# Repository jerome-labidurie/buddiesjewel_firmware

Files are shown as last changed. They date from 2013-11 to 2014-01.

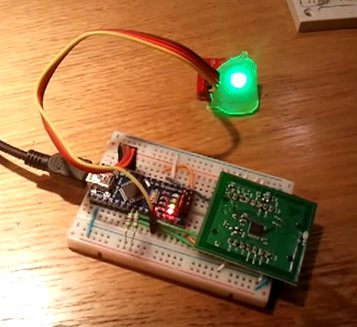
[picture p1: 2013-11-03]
hardware/Photos/Proto_v1_5.jpg

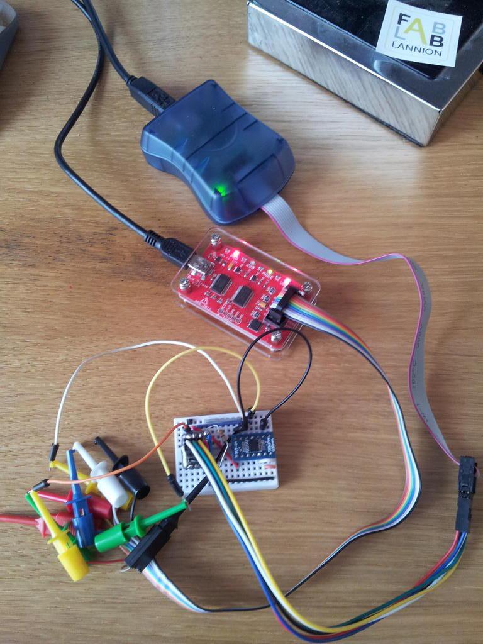
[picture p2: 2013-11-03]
hardware/Photos/Proto_v2.jpg

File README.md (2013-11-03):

buddiesjewel_firmware
=====================

Firmware (arduino, attiny45) for BuddiesJewel project

http://fablab-lannion.org/wiki/index.php?title=BuddiesJewel

* attiny45/ : firmware attiny45 et RF430CL330H
* BlinkM/ : archive de BlinkM et outils de flashage
* hardware/ : schémas
* serial2rgb/ : commande d'une led rgb par liason série (via arduino)
* tag2rgb/ : lecture couleur dans un tag et commande rgb (shield nfc reader)
* TI_dynamic_tag/ : utilisation par un arduino du RF430Cl330H

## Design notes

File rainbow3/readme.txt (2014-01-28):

/* ************************************************************ *
 *                    rainbow3                                  *
 *  README                                                      *
 *  desc: for attiny45 (8 Mhz), NeoPixel connected on pin 6     *
 *        run a rainbow of colors until detection of a pressure *
 *        on the push button (pin 5) that stops the rainbow on  *
 *        the current color.                                    *
 *        Another pressure detection will start over the rainbow*
 *                                                              *
 * pinout:                                                      *
 *               ______                                         *
 *        n/a --|1    8|-- Vcc                                  *
 *        n/a --|2    7|-- Debug LED                            *
 *        n/a --|3    6|-- NeoPixel Din                         *
 *        gnd --|4____5|-- push button                          *
 *                                                              *
 * ************************************************************ */

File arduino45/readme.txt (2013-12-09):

Use the attiny45 as an arduino (ie arduino libs)

Install
-------

Install attiny support for arduibo IDE
See here http://hlt.media.mit.edu/?p=1695
Or here http://code.google.com/p/arduino-tiny/
- board type: Attiny45 (internal 8MHz clock)
Burn bootloader (to set the fuses)

Install Adafruit NeoPixel lib
https://github.com/adafruit/Adafruit_NeoPixel

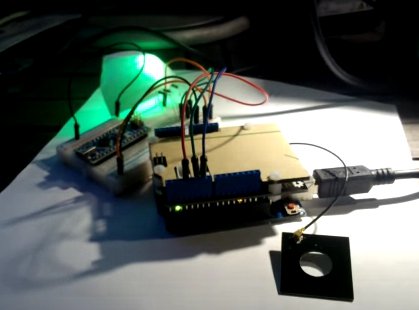
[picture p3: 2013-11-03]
hardware/Photos/Proto_v1.jpg

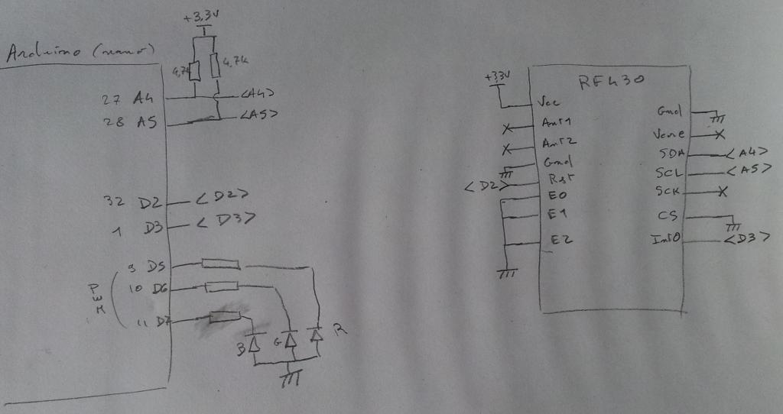
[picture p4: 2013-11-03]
hardware/schema_nano+rf430.jpg

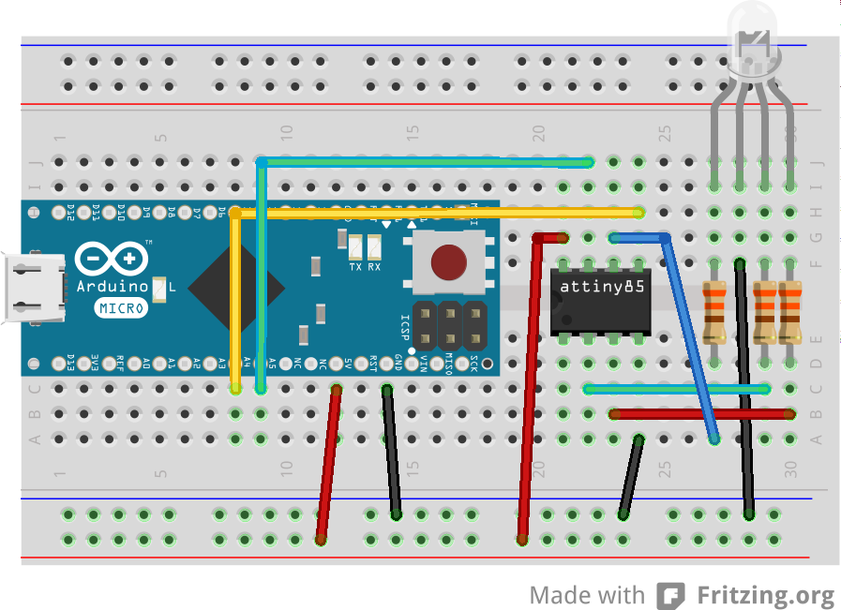
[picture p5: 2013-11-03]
hardware/arduino_BlinkM_bb.png

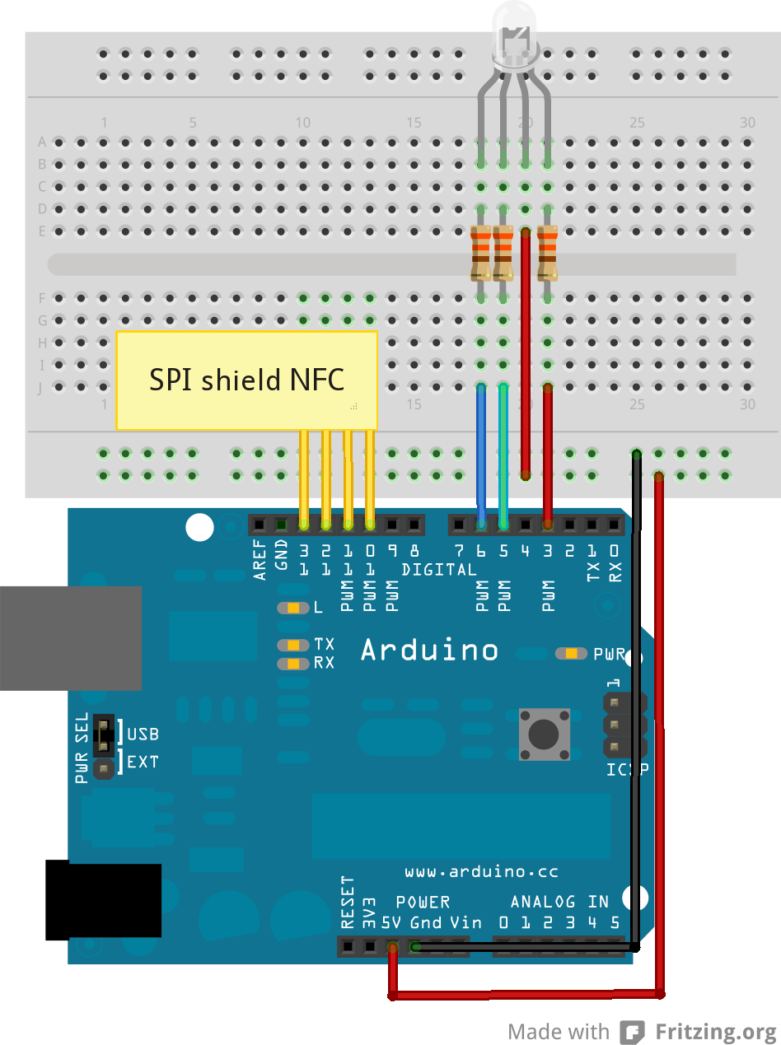
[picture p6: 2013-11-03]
hardware/tag2rgb_bb.png

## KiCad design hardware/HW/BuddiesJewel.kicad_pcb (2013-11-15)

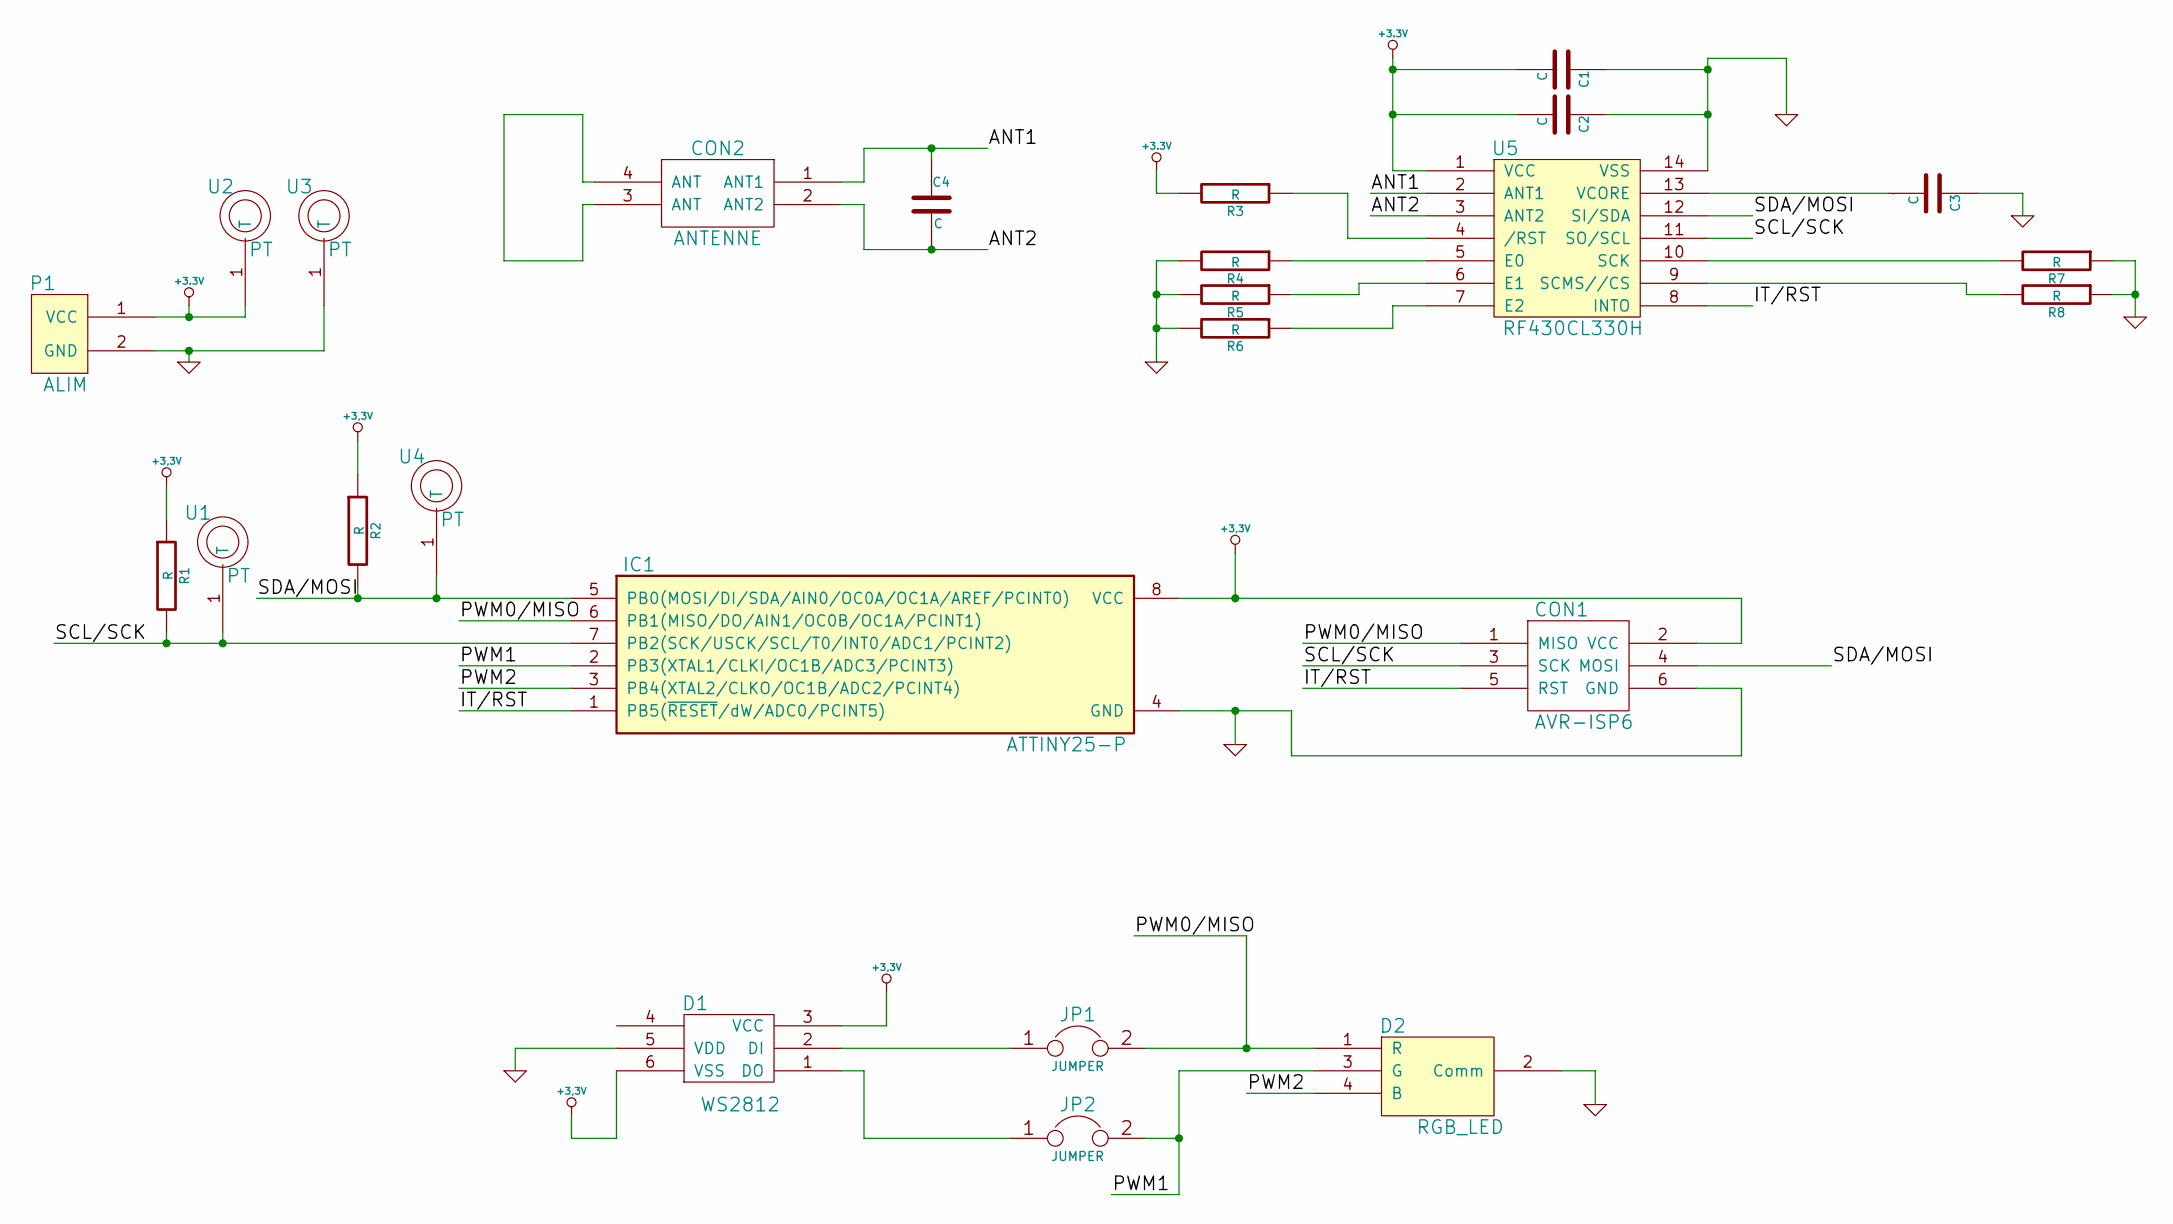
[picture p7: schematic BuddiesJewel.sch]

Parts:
C1, C2, C3, C4: C
CON1: AVR-ISP6
CON2: ANTENNE
D1: WS2812
D2: RGB_LED
IC1: ATTINY25-P; DIP8
JP1, JP2: JUMPER
P1: ALIM
R1, R2, R3, R4, R5, R6, R7, R8: R
U1, U2, U3, U4: PT
U5: RF430CL330H

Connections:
/ANT1: C4.1, CON2.1 (ANT1), U5.2 (ANT1)
/ANT2: C4.2, CON2.2 (ANT2), U5.3 (ANT2)
/IT/RST: CON1.5 (RST), IC1.1 (PB5(~RESET~/dW/ADC0/PCINT5)), U5.8 (INTO)
/PWM0/MISO: CON1.1 (MISO), D2.1 (R), IC1.6 (PB1(MISO/DO/AIN1/OC0B/OC1A/PCINT1)), JP1.2
/PWM1: D2.3 (G), IC1.2 (PB3(XTAL1/CLKI/OC1B/ADC3/PCINT3)), JP2.2
/PWM2: D2.4 (B), IC1.3 (PB4(XTAL2/CLKO/OC1B/ADC2/PCINT4))
/SCL/SCK: CON1.3 (SCK), IC1.7 (PB2(SCK/USCK/SCL/T0/INT0/ADC1/PCINT2)), R1.2, U1.1, U5.11 (SO/SCL)
/SDA/MOSI: CON1.4 (MOSI), IC1.5 (PB0(MOSI/DI/SDA/AIN0/OC0A/OC1A/AREF/PCI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), R2.2, U4.1, U5.12 (SI/SDA)
GND: C1.1, C2.1, C3.1, CON1.6 (GND), D1.5 (VDD), D2.2 (Comm), IC1.4 (GND), P1.2 (GND), R4.2, R5.2, R6.2, R7.1, R8.1, U3.1, U5.14 (VSS)
unnamed: R6.1, U5.7 (E2)
unnamed: R5.1, U5.6 (E1)
unnamed: R4.1, U5.5 (E0)
unnamed: D1.2 (DI), JP1.1
unnamed: R8.2, U5.9 (SCMS//CS)
unnamed: R7.2, U5.10 (SCK)
unnamed: R3.1, U5.4 (/RST)
unnamed: C3.2, U5.13 (VCORE)
unnamed: CON2.3 (ANT), CON2.4 (ANT)
unnamed: D1.1 (DO), JP2.1

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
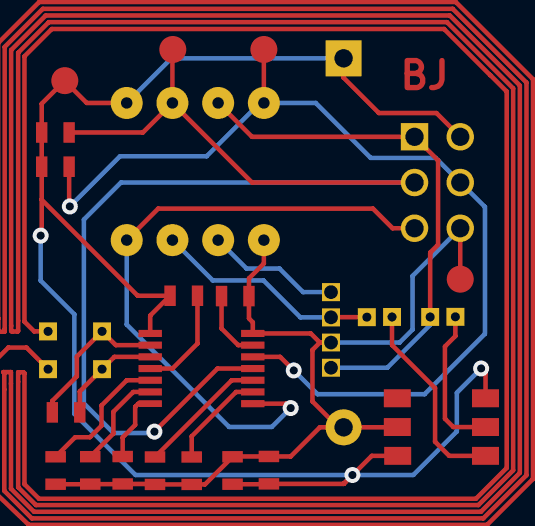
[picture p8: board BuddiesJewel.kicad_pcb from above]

Board: 2 copper layers, 25 parts (0 on the bottom side), 20 nets.

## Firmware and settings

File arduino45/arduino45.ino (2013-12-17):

/*********************************************************************
 * BuddiesJewel prototype with ATtiny45/RF430CL330H
 *********************************************************************
 * Copyright: (c) 2013 Jérôme Labidurie
 * Licence:   GNU General Public Licence version 3
 * Email:     jerome.labidurie at gmail.com
 *********************************************************************
 * This file is part of BuddiesJewel.
 * 
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
 * ATtiny45
 *                                      ---v---
 *         (PCINT5/RESET/ADC0/dW) PB5 -| 1   8 |- VCC
 *  (PCINT3/XTAL1/CLKI/OC1B/ADC3) PB3 -| 2   7 |- PB2 (SCK/USCK/SCL/ADC1/T0/INT0/PCINT2)
 *  (PCINT4/XTAL2/CLKO/OC1B/ADC2) PB4 -| 3   6 |- PB1 (MISO/DO/AIN1/OC0B/OC1A/PCINT1)
 *                                GND -| 4   5 |- PB0 (MOSI/DI/SDA/AIN0/OC0A/OC1A/AREF/PCINT0)
 *                                      -------
 * 
 * RF430CL330H
 *        ----v---
 *  Vcc -|  1  14 |- Gnd
 *   A1 -|  2  13 |- Vcore
 *   A2 -|  3  12 |- SDA
 * /RST -|  4  11 |- SCL
 *   E0 -|  4  10 |- SCK
 *   E1 -|  6   9 |- /CS
 *   E2 -|  7   8 |- Int
 *        --------
 * 
 * AT45    RF430   NeoPixel
 * -------------------
 * PB1 --- INT0
 * PB2 --- SCL
 * PB0 --- SDA
 * GND --- Gnd,E0,E1,E2,/CS,
 * PB4 ----------- In
 * 
 *********************************************************************/

#include <avr/io.h>
#include <util/delay.h>
#include <avr/interrupt.h>
#include <avr/sleep.h>

#include "usiTwiMaster.h"
#include "RF430CL330H.h"

#include <Adafruit_NeoPixel.h>
#include <EEPROM.h>

#define MESSAGEBUF_SIZE       10

#define NEO 4
#define QUICK 100

#define  CONTROL_REG_VALUE RF_ENABLE | INT_ENABLE | INTO_HIGH | INTO_DRIVE
// predefined colors
//      NAME      0xRRGGBB
#define BLUE      0x0000FF
#define GREEN     0x00FF00
#define RED       0xFF0000
#define YELLOW    0xFFFF00
#define CYAN      0x00FFFF
#define MAGENTA   0xFF00FF

// Parameter 1 = number of pixels in strip
// Parameter 2 = pin number (most are valid)
// Parameter 3 = pixel type flags, add together as needed:
//   NEO_KHZ800  800 KHz bitstream (most NeoPixel products w/WS2812 LEDs)
//   NEO_KHZ400  400 KHz (classic 'v1' (not v2) FLORA pixels, WS2811 drivers)
//   NEO_GRB     Pixels are wired for GRB bitstream (most NeoPixel products)
//   NEO_RGB     Pixels are wired for RGB bitstream (v1 FLORA pixels, not v2)
Adafruit_NeoPixel led = Adafruit_NeoPixel(1, NEO, NEO_GRB + NEO_KHZ800);

uint8_t temp = 0;               /** temporary variable */
uint16_t value = 0;             /** used to store read values from registers */
uint32_t savedColor = 0x000000; /** color read from eeprom */

/** do some quick blinks
 * @param n number of blinks
 * @param color the color to blink (created by Adafruit_NeoPixel.Color() )
 */
void quickBlink (uint8_t n, uint32_t color)
{
   while (n-- != 0)
   {
      led.setPixelColor (0, color );
      led.show();
      _delay_ms (QUICK);
      led.setPixelColor (0, 0 );
      led.show();
      _delay_ms (QUICK);
   }
} //quickBlink


/** read register from RF430
 * @param reg the register address to read. See RF430CL330H.h.
 * @param pValue pointer to the read value
 * @return USI_TWI_Get_State_Info. See usiTwiMaster.h for error codes.
 */
uint8_t readRegister (uint16_t reg, uint16_t* pValue)
{
   uint8_t messageBuf[MESSAGEBUF_SIZE];
   
   // write register adress
   messageBuf[0] = RF430_I2C_ADDRESS << TWI_ADR_BITS;
   messageBuf[1] = reg >> 8;
   messageBuf[2] = reg & 0xFF;
   USI_TWI_Start_Transceiver_With_Data( messageBuf, 3 );
   // read register
   messageBuf[0] = ( RF430_I2C_ADDRESS << TWI_ADR_BITS ) | (RF430_I2C_READBIT);
   USI_TWI_Start_Transceiver_With_Data( messageBuf, 3 );
   
   *pValue = (messageBuf[1] << 8) | messageBuf[2];
   
   return USI_TWI_Get_State_Info();
} // readRegister

/** read NFC data from RF430 
 * 
 * If active, RF must be disabled before. eg: writeRegister (CONTROL_REG, 0);
 * Note: offset+length must be < 0x0BFF. Else we go into registers.
 * 
 * @param offset the offset in NFC tag data
 * @param length the length to be read
 * @param data byte array for the read data. Must be at least length+1. Read data begins at data[1]
 * @return USI_TWI_Get_State_Info. See usiTwiMaster.h for error codes.
 * 
 */
uint8_t readData (uint16_t offset, uint16_t length, uint8_t* data)
{
   // write data address
   data[0] = RF430_I2C_ADDRESS << TWI_ADR_BITS;
   data[1] = offset >> 8;
   data[2] = offset & 0xFF;
   USI_TWI_Start_Transceiver_With_Data( data, 3 );
   // read register
   data[0] = ( RF430_I2C_ADDRESS << TWI_ADR_BITS ) | (RF430_I2C_READBIT);
   USI_TWI_Start_Transceiver_With_Data( data, length + 1 );

   return USI_TWI_Get_State_Info();
} // readData

/** write a register to RF430
 * @param reg the register address to write. See RF430CL330H.h.
 * @param value the value to be written.
 * @return USI_TWI_Get_State_Info. See usiTwiMaster.h for error codes.
 */
uint8_t writeRegister (uint16_t reg, uint16_t value)
{
   uint8_t messageBuf[MESSAGEBUF_SIZE];
   
   // write register adress
   messageBuf[0] = RF430_I2C_ADDRESS << TWI_ADR_BITS;
   messageBuf[1] = reg >> 8;
   messageBuf[2] = reg & 0xFF;
   messageBuf[3] = value & 0xFF;
   messageBuf[4] = value >> 8;
   USI_TWI_Start_Transceiver_With_Data( messageBuf, 5 );
   
   return USI_TWI_Get_State_Info();
} // writeRegister


/** Go to designated color
 * 
 * Fade from current color. Each component (R,G,B) are (inc|dec)remented
 * by one step up to the given color.
 * 
 * @param color to go
 * @param wait delay (ms) between each step
 */
void gotoColor (uint32_t color, uint8_t wait)
{
   uint32_t cColor = led.getPixelColor(0);  /** current color */
   uint8_t rc = cColor >> 16;               /** current red */
   uint8_t gc = cColor >> 8 & 0xFF;         /** current green */
   uint8_t bc = cColor & 0xFF;              /** current blue */
   int8_t  ri=1,gi=1,bi=1;                  /** inc/dec for each component */
   
   // compute inc or dec for each component
   if ( (rc) > (color>>16) ) {
      ri = -1;
   }
   if ( (gc) > (color>>8&0xFF) ) {
      gi = -1;
   }
   if ( (bc) > (color&0xFF) ) {
      bi = -1;
   }
   
   // goto
   while (cColor != color) {
      if (rc != (color>>16))
         rc += ri;
      if (gc != (color>>8&0xFF))
         gc += gi;
      if (bc != (color&0xFF))
         bc += bi;
      cColor = led.Color (rc,gc,bc);
      led.setPixelColor (0, cColor);
      led.show();
      delay(wait);
   }
} // gotoColor

/** interrupt service routine
 * called when PCINT changes state
 */
ISR(PCINT0_vect)
{
//    quickBlink (1, BLUE ); // quick 1 blue blink
   // nothing to do, we just wake up
   return;
} // ISR(PCINT0_vect) 

/****** MAIN ******/
   
void setup()
{
   led.begin();
   quickBlink (1, BLUE ); // quick 1 blue blink
   
   USI_TWI_Master_Initialise();
   temp = readRegister  (VERSION_REG, &value);
   quickBlink (value>>8,   BLUE );
   quickBlink (value&0xFF, BLUE );

   // read color from eeprom
   savedColor = ((uint32_t)EEPROM.read(0)<<16) | ((uint32_t)EEPROM.read(1)<<8) | EEPROM.read(2);
   
   // Initialize pixel to saved color
   gotoColor (savedColor,10);
   // TODO: Initialize NFC tag with color (and NDEF?)
   
   temp = writeRegister (INT_ENABLE_REG, EOW_INT_ENABLE);
   temp = writeRegister (CONTROL_REG,    CONTROL_REG_VALUE );
   temp = readRegister  (CONTROL_REG,    &value);
   
   /** Power budget reduction */
   ADCSRA &= ~_BV(ADEN);            // disable ADC
   ACSR   |=  _BV(ACD);             // switch Analog Comparator OFF
   // Configure Power Reduction Register (See p39)
   PRR    |=  _BV(PRADC) | _BV(PRTIM0); // switch off ADC clock, Timer0
   // disable BOD by software (timed sequence see p38)
   // useless if BOD not set by fuses
   sleep_bod_disable();


} // setup

void loop()
{
   uint8_t data[MESSAGEBUF_SIZE]; /** array to store read NDEF data */
   uint32_t readColor = 0;

   /** initialize attiny45 interrupts */
   PCMSK |= _BV(PCINT1); // enable interrupt for PCINT1
   GIMSK |= _BV(PCIE);   // enable Pin Change interrupts
   sei(); // enable global interrupts

   /** go to sleep */
   set_sleep_mode(SLEEP_MODE_PWR_DOWN); // sleep mode is set here
   sleep_enable();
   sleep_cpu(); // go to sleep

   // System continues execution here when wake up occurs
   cli();                // wake up here, disable interrupts
   GIMSK &= ~_BV(PCIE);  // disable PCIE
   sleep_disable();               
   sei();                // enable interrupts again (but PCIE is disabled from above)
//    quickBlink (1, GREEN);

   // Wait for no rf field present,
   // well not needed as EOW int occurs when RF field is off after a write
//    temp = readRegister  (CONTROL_REG,    &value);
//    while ( (value & RF_BUSY) != 0) {
//       _delay_ms (1);
//       temp = readRegister  (CONTROL_REG,    &value);
//    }
   // disable RF
   // TODO: we might only disable the right bit !
   temp = writeRegister (CONTROL_REG, 0x0);
   // ack every interrupts (yes this is a bit harsh)
   temp = writeRegister (INT_FLAG_REG, 0x00FF );
   // read ndef data mime type (should be "bijou")
   temp = readData (0x1C + 0x20, 6, data);
   if ( strncmp ((char*)data+1, "bijou", 5) == 0) {
      // 0x1C: NDEF begin 0x25: offset to color
      temp = readData (0x1C + 0x25, 4, data);
      readColor = led.Color (data[2], data[3], data[4]);
      gotoColor (readColor,10);
      // if needed, save new color in eeprom
      if (savedColor != readColor) {
         EEPROM.write(0, readColor >> 16);
         EEPROM.write(1, (readColor >> 8) & 0xFF);
         EEPROM.write(2, readColor & 0xFF);
         savedColor = readColor;
      }
   }
//    else quickBlink(1,RED);
   // enable RF
   temp = writeRegister (CONTROL_REG, CONTROL_REG_VALUE );
} // loop

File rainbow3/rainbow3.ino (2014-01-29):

#include <avr/io.h>
#include <avr/interrupt.h>
#include <Adafruit_NeoPixel.h>

#define RAINBOWING_LED_PIN 0      /* Physical Pin 5: for PCINT1: Play/Stop Pin      */
#define LED_PIN            1      /* Physical Pin 6: LED connection                 */
#define DEBUG_PIN          2      /* Physical Pin 7: debugging with a led:          */
                                  /*                 HIGH when the button is pushed */
                                  /*                 LOW  otherwise                 */ 
                                  
#ifdef TRUE
#  undef TRUE
#endif
#ifdef FALSE
#  undef FALSE
#endif
#ifdef UP
#  undef UP
#endif
#ifdef DOWN
#  undef DOWN
#endif

#define TRUE  0x01
#define FALSE 0x00
#define UP    1
#define DOWN  0

// Parameter 1 = number of pixels in led
// Parameter 2 = pin number (most are valid)
// Parameter 3 = pixel type flags, add together as needed:
//   NEO_KHZ800  800 KHz bitstream (most NeoPixel products w/WS2812 LEDs)
//   NEO_KHZ400  400 KHz (classic 'v1' (not v2) FLORA pixels, WS2811 drivers)
//   NEO_GRB     Pixels are wired for GRB bitstream (most NeoPixel products)
//   NEO_RGB     Pixels are wired for RGB bitstream (v1 FLORA pixels, not v2)
Adafruit_NeoPixel   led           = Adafruit_NeoPixel(1, LED_PIN, NEO_GRB + NEO_KHZ800);
volatile unsigned char rainbowing = TRUE;
volatile unsigned char flag       = DOWN; 
volatile unsigned char count      = 0; 

/** interrupt service routine
 * called when PCINT changes state
 */
void stop_rainbow()
{
   rainbowing=!rainbowing;
} // stop_rainbow()


void setup() {
  pinMode(DEBUG_PIN,OUTPUT);

  led.begin();
  led.show(); // Initialize all pixels to 'off'
  rainbowing = TRUE; // activate the rainbow 
  count=0;
  flag       = DOWN; // no detected interrupt yet
  attachInterrupt(RAINBOWING_LED_PIN, stop_rainbow, FALLING);
}

void loop() {
  uint8_t wait = 200;  

  if(digitalRead(RAINBOWING_LED_PIN)==LOW) {
    digitalWrite(DEBUG_PIN,LOW);
  }
  else {
    digitalWrite(DEBUG_PIN,HIGH);
  }
  
  if(rainbowing) {
    led.setPixelColor(0, Wheel(count++));
    led.show();
  }
  delay(wait);
}


// Input a value 0 to 255 to get a color value.
// The colours are a transition r - g - b - back to r.
uint32_t Wheel(byte WheelPos) {
  if(WheelPos < 84) {
    return led.Color(255 - WheelPos * 3, 0, WheelPos * 3);
  } else if(WheelPos >=84 && WheelPos < 88) { // fix blue color
    return led.Color(0, 0, 255);  
  } else if(WheelPos < 170) {
    WheelPos -= 85;
    return led.Color(0, WheelPos * 3, 255 - WheelPos * 3);
  } else {
    WheelPos -= 170;
    return led.Color(WheelPos * 3, 255 - WheelPos * 3, 0);
  }
}

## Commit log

2013-04-05 tag2rgb scheme
    [tag2rgb.fz]
2013-07-10 Add hardware - new version for tag2rgb - blinkm connection with arduino
    [arduino_BlinkM.fzz, tag2rgb.fzz]
2013-07-10 correct fuse to be modified !
2013-10-02 arduino+RF430 bis
2013-11-15 Add kicad hardware scheme
    [BuddiesJewel.kicad_pcb, BuddiesJewel.sch]
2013-11-18 change "RGB_LED (4)" D2 connector to "EXT_LED (3)" change ATtiny/RF430/WS2812/CON1 connections
    [BuddiesJewel.kicad_pcb, BuddiesJewel.sch]
2013-11-19 new antenna and some enhanced stuff
    [BuddiesJewel.kicad_pcb]
2013-11-20 new PCB revision
    [BuddiesJewel.kicad_pcb]
2013-11-29 BJ_PCB 1.2
    - change track width to class 2 (from .254mm to .5mm), except next to the RF430
    - rearrange component locations
    - add R,C stuff close to the LED WS2812 (NeoPixel) as it is on the little adaFruit NeoPixel board
2013-11-29 (minor) just move PCB .25mm to the right
    [BuddiesJewel.kicad_pcb]
2013-11-29 add svg generated files for PCB_1.2
2013-11-29 pcb modif following svg file generation
    [BuddiesJewel.kicad_pcb]
2013-12-01 Use DIP footprint for TI chip Reroute to use 0,5mm nets
    [BuddiesJewel.kicad_pcb, BuddiesJewel.sch]
2013-12-02 (minor) modif on pcb
    [BuddiesJewel.kicad_pcb]
2013-12-02 PCB_v1.3
    - fix some bugs (missed connection, bad nodes...)
    - remove some useless vias
    - redo the antenna (just in case where that could work ;)
    [BuddiesJewel.kicad_pcb]
2013-12-02 PCB_v1.3.1
    (minor) move C2 to the good position
    [BuddiesJewel.kicad_pcb]
2013-12-03 PCB_v1.4
    **will be used for our first etch**
    - increase track width to .8mm (antenna tracks still in .5mm)
    - remove the LED_DI jumper then replaced with a 0 ohm resistor (freed space)
    [BuddiesJewel.kicad_pcb, BuddiesJewel.sch]
2013-12-04 attiny45 as arduino
2013-12-09 Add another url for attiny arduino core
2013-12-10 Use interrupts to get tag color when written
2013-12-12 Enable power down mode
2013-12-14 A bit more power reduction

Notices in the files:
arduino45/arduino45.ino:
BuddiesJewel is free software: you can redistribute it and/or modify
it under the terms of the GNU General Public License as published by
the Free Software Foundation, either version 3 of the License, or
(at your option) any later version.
